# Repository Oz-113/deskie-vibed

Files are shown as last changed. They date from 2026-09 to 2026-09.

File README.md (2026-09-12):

# Deskie

I had deepseek create this project based on my initial prototype.

A desk-side volume and system-monitor controller for the **ESP32-S3 (N16R8)**, built around a
240 × 240 round **GC9A01** display. An animated background plays behind a set of radial gauges,
the rotary encoder drives the Windows volume and media transport, and the device is fed live
CPU / RAM / GPU data by a small Python bridge over the USB serial link.

> One USB cable, no extra wiring, no drivers: the board appears as a serial port and the
> Python script does the PC-side work.

---

## Features

* **Arc-based UI** over a dimmed, still-playing animation — resource gauges, detail pages,
  a volume gauge, transport controls and an animation picker all share one visual language.
* **Real Windows volume**, read *and* written, plus mute and the media keys
  (the firmware sends intent; the PC performs it).
* **Live metrics**: CPU load / clock / threads, RAM used-total, GPU load, GPU temperature,
  hotspot, memory temperature, GPU board power, fan speed, and VRAM used-total.
* **Now-playing ticker** on the idle screen with a rotating vector ornament, all tinted from
  the animation's palette.
* **Audio reactive spectrum**: eight log-spaced bands drawn as a mirrored radial ring over the
  upper half of the display, with a beat flash. All the DSP runs on the PC, so the board only
  receives eight small numbers.
* **Animations** stored in LittleFS as raw RGB565 frames, uploadable straight from the
  Arduino IDE.
* **Dual-core FreeRTOS firmware**: serial + input on core 0, rendering on core 1, with
  queues between them.
* **Graceful degradation on the PC side**: without LibreHardwareMonitor you still get CPU,
  RAM, GPU and VRAM usage from built-in Windows APIs.

---

## Architecture

```
   ┌────────────────────────────┐   USB-Converter serial (921600 8N1) ┌────────────────────┐
   │  ESP32-S3  N16R8           │ <─────────────────────────────────> │  PC                │
   │  GC9A01 240x240 round TFT  │                                     │  controller.py     │
   │  rotary encoder + buttons  │   metrics  ->  S,/E,/V,/T,          │  psutil            │
   │  LittleFS: RGB565 frames   │   commands <-  VSET,/MUTE,/MK,/REQ  │  LHM / PDH / pycaw │
   └────────────────────────────┘                                     └────────────────────┘
```

* The **PC** gathers metrics, owns the audio, and injects the media keys.
* The **board** owns the UI, the animation and all input, and never blocks on the link:
  it renders at its own pace and simply reflects the newest values it has.

---

## Repository layout

```
VolumeControllerUART/
├─ VolumeControllerUART.ino   setup + the three pinned FreeRTOS tasks
├─ config.h                   pins, animation palette, gauge geometry, timings
├─ state.h / state.cpp        shared runtime state + mutex + the two queues
├─ comms.h / comms.cpp        serial line protocol  (core 0)
├─ input.h / input.cpp        encoder ISR + buttons (core 0)
├─ display.h / display.cpp    TFT_eSPI wrapper: sprite, gauges, vector icons
├─ anim.h / anim.cpp          LittleFS frame player (core 1)
├─ ui.h / ui.cpp              screens, navigation state machine, rendering
├─ partitions.csv             custom partition layout (large LittleFS area)
├─ data/                      the animation frames (*.raw, 115200 B each)
└─ pc/
   ├─ controller.py           the headless PC bridge
   ├─ requirements.txt
   └─ README.md
```

---

## Hardware

| Function | GPIO | Notes |
|---|---|---|
| Display MOSI / SCLK | 11 / 12 | GC9A01, HSPI, 27 MHz |
| Display CS / DC / RST | 10 / 14 / 15 | configured in TFT_eSPI's `User_Setup.h` |
| Rotary encoder A / B | 5 / 4 | quadrature, interrupt driven |
| Encoder push button | 17 | short press = OK/enter, long press = back |
| Media play / next / prev | 6 / 7 / 8 | work from any screen, active-low |
| Shortcut: monitor | 21 | reserved, optional |
| Shortcut: volume | 38 | reserved, optional |
| Shortcut: media | 47 | reserved, optional |
| Shortcut: gallery | 48 | reserved, optional |

The display pins live in the **TFT_eSPI** library's `User_Setup.h`, not in this sketch — that is
normal for TFT_eSPI and keeps the driver configuration with the library.

The four "shortcut" pins are wired as `INPUT_PULLUP` and are active-low, so an **unwired pin
simply reads HIGH and never fires** — you can leave them unconnected and fit buttons later.
Set `ENABLE_SHORTCUT_BUTTONS 0` in `config.h` to release them.

The PC link uses the native USB port of the board (USB-CDC): one cable carries both flashing
and the data link.

---

## Build & flash

Arduino IDE 2.x, **esp32** board package **3.3.11**, board **ESP32S3 Dev Module**:

| Setting | Value |
|---|---|
| Flash Size | 16MB (128Mb) |
| PSRAM | OPI PSRAM |
| Partition Scheme | **Custom** (uses `partitions.csv`) |
| USB Mode | Hardware CDC and JTAG |
| **USB CDC On Boot** | **Enabled** |
| Upload Speed | 921600 |
| CPU Frequency | 240MHz |
| Loop Core | Core 1 *(default)* |

> `USB CDC On Boot` selects which USB port the firmware talks on. **Enabled** = the native
> USB-CDC port (labelled `USB` on most devkits). If you set it to **Disabled**, `Serial` moves
> to UART0 (GPIO43/44) and you must use the board's `UART` (CH34x/CP210x bridge) port instead.
> Getting this pair wrong is the one thing that makes the link look dead — see *Troubleshooting*.

Steps:

1. Open `VolumeControllerUART.ino`.
2. Upload the sketch.
3. Upload the filesystem (**Tools ▸ ESP32 LittleFS Data Upload**). `data/` holds the animation
   frames and is a few MB, so this takes a moment.
4. Start the PC bridge (below).

Typical footprint: **~418 KB flash, ~24 KB static RAM** plus two 115 KB PSRAM frame buffers.

---

## The serial protocol

Plain ASCII, one message per line, `\n`-terminated, comma separated. Every value is an integer
and **`-1` means "unavailable"**. Unrecognised lines (such as firmware boot logs) are ignored
by both sides.

### PC → board

| Message | Meaning |
|---|---|
| `H,<ver>` | handshake / protocol version (the board answers with its own `H,1`) |
| `S,<cpu>,<ram>,<gpu>,<vram>` | summary percentages |
| `E,<13 values>` | detail payload, fixed order (see below) |
| `V,<volume>,<mute>` | current master volume 0..100 and mute flag |
| `T,<state>,<artist>\|<title>` | now playing; state 0 none / 1 playing / 2 paused |
| `A,<b0>..<b7>,<pulse>` | audio spectrum: eight band levels (0..100) plus a beat pulse |
| `P` | ping (the board answers `PONG`) |

`E` field order:

| # | field | unit | # | field | unit |
|---|---|---|---|---|---|
| 0 | CPU temperature | ×10 | 7 | GPU hotspot | ×10 |
| 1 | CPU package power | ×10 | 8 | GPU memory temperature | ×10 |
| 2 | CPU clock | MHz | 9 | GPU board power | ×10 |
| 3 | CPU threads | count | 10 | GPU fan | % |
| 4 | RAM used | MB | 11 | VRAM used | MB |
| 5 | RAM total | MB | 12 | VRAM total | MB |
| 6 | GPU temperature | ×10 | | | |

### Board → PC

| Message | Meaning |
|---|---|
| `H,<ver>` | boot announce + reply to the PC handshake |
| `VSET,<n>` | absolute volume target from the volume wheel (0..100) |
| `VOL,±n` | relative step — still accepted by the PC, no longer sent by the board |
| `MUTE,<0\|1>` | toggle mute |
| `MK,PP` / `MK,N` / `MK,P` | media play-pause / next / previous |
| `REQ,<C\|R\|G\|V>` | "send the detail payload for CPU/RAM/GPU/VRAM" |
| `PG,<PAGE>` | which screen is open (`MONITOR`/`VOLUME`/`MEDIA`/`GALLERY`) |
| `PONG` | answer to `P` |

The link is considered down after 1.5 s without traffic; the monitor page shows `LINK DOWN` and
the board keeps re-announcing `H,1` every 2 s until it hears from the PC.

> Why `VSET` and not `VOL,±1`? `GetMasterVolumeLevelScalar()` on Windows lags slightly behind a
> write, so a PC-side read-modify-write drifts and can even move the volume the wrong way. The
> board already knows the value it wants, so it sends the absolute target and the PC just applies
> it.

---

## The PC bridge

Headless — no GUI, one process, run it whenever you want the board connected.

```powershell
cd pc
python -m venv .venv
.\.venv\Scripts\Activate.ps1
pip install -r requirements.txt

python controller.py --scan      # find the port the board actually answers on
python controller.py             # auto-detect and run (Ctrl+C to stop)
python controller.py --port COM5 -v
```

### Flags

| Flag | Purpose |
|---|---|
| `--port COM5` | pin the port (default: probe every port for the board) |
| `--list` | list serial ports with VID:PID |
| `--scan` | probe every port for the board and exit |
| `--selftest` | test master-volume read **and** write, then exit |
| `--rate N` | metric updates per second sent to the board (default 1) |
| `--audio-test` | print the live audio band levels (no serial port) and exit |
| `--audio-rate N` | spectrum updates per second sent to the board (default 25) |
| `--audio-gain DB` | extra gain applied to every band (default 0) |
| `--no-audio` | disable the audio reactive spectrum |
| `--np-proc NAME` | extra media process to watch for now playing (repeatable) |
| `--no-volume` / `--no-nowplaying` | disable those features |
| `--no-pdh` / `--no-lhm` | disable a GPU backend |
| `--lhm-dll PATH` | point at `LibreHardwareMonitorLib.dll` explicitly |
| `--dry-run` | exercise every backend without opening a port |
| `--run-seconds N` | exit after N seconds (handy for testing) |
| `--verbose` / `-v` | print every protocol line in both directions |

### Where the numbers come from

| Data | Source | Needed install |
|---|---|---|
| CPU load, clock, threads, RAM used/total | `psutil` | `pip install psutil` |
| GPU utilisation | LibreHardwareMonitor, else Windows PDH counters | none (PDH is built in) |
| VRAM used | LibreHardwareMonitor, else PDH `Dedicated Usage` | none |
| VRAM total | `HardwareInformation.qwMemorySize` from the registry | none |
| CPU / GPU temperature, hotspot, memory temp, board power, fan | LibreHardwareMonitor | **LibreHardwareMonitor** + `pip install pythonnet` |
| Master volume / mute | `pycaw` (Core Audio) | `pip install pycaw comtypes` |
| Media keys | `user32.keybd_event` | none |
| Now playing | Windows SMTC when `winsdk`/`winrt` is importable, else media window titles | none for the fallback |

Everything is layered, so a missing optional backend degrades to `--` on the display instead of
failing to start.

#### Installing the optional sensor backend

1. Download the latest release of
   [LibreHardwareMonitor](https://github.com/LibreHardwareMonitor/LibreHardwareMonitor) and
   extract the **whole folder** to `C:\Program Files\LibreHardwareMonitor\`
   (it must contain `LibreHardwareMonitorLib.dll`, `HidSharp.dll` and `WinRing0x64.sys`).
2. **Unblock the extracted files** — they carry Windows' "downloaded from the internet" mark and
   .NET then refuses to load the DLL (`0x80131515`, "network location"). In an **admin**
   PowerShell:

   ```powershell
   Get-ChildItem "C:\Program Files\LibreHardwareMonitor" -Recurse | Unblock-File
   ```
3. Run `LibreHardwareMonitor.exe` **as administrator** once, so its kernel driver is installed.
   Leaving it running is the simplest option.
4. `pip install pythonnet` and restart the bridge. It auto-detects the DLL and logs
   `LibreHardwareMonitor loaded: ...`; otherwise pass `--lhm-dll`.

---

## Screens & controls

**turn** = move / change value · **short press** = OK / enter · **long press** = back one level

| Screen | Shows | Controls |
|---|---|---|
| **IDLE** | the animation, the audio spectrum ring, and a now-playing ticker with a rotating vector ornament | turn = open the menu |
| **MENU** | four page tiles | turn = move, OK = open, hold = close |
| **MONITOR** | CPU / RAM / GPU / VRAM gauges spread around the ring, each with its `%`, the selected one large in the centre | turn = pick, OK = detail, hold = menu |
| **DETAIL** | one component full screen: big gauge plus temperature / power / clock / threads / used-total | turn = cycle component, hold = monitor |
| **VOLUME** | a big gauge driven by the real Windows volume | turn = adjust, OK = mute, hold = menu |
| **MEDIA** | now playing plus prev / play-pause / next | turn = pick, OK = go, hold = menu |
| **GALLERY** | a segmented ring with a live preview of each animation | turn = preview, OK = keep, hold = cancel |

The dimmed animation keeps playing behind every overlay, **MONITOR never times out**, `DETAIL`
falls back to `MONITOR` after 20 s, and the other pages return to the animation after 8 s of
inactivity. The four dedicated media buttons work from any screen.

---

## Firmware architecture

| Task | Core | Prio | Responsibility |
|---|---|---|---|
| `taskComm` | 0 | 4 | serial RX line assembly, TX queue drain, link watchdog |
| `taskInput` | 0 | 5 | encoder sampling, button debounce, short/long press |
| `taskRender` | 1 | 6 | frame load, dim, gauges, `pushSprite` |

* `taskInput` posts `InputEvent`s onto `gInputQ`; `uiRender()` pumps that queue and feeds each
  event to `uiHandleEvent()` before drawing.
* The renderer posts `OutMsg`s onto `gOutQ`; `taskComm` drains those to the PC.
* The only shared state is one `Runtime` struct behind a mutex, snapshotted once per frame.
* `loop()` is intentionally empty — all work is in the pinned tasks.

**Rendering budget.** The panel bus runs at 27 MHz, so a full 240 × 240 frame takes ~34 ms to
push; that caps the display at roughly **29 fps** whatever the animation's `fps` says. Rendering
is also "dirty" filtered: if neither a new frame was loaded nor any displayed value changed, the
frame simply is not re-pushed.

---

## Customising

Almost everything you would want to change lives in **`config.h`**.

### The colour palette

Each animation carries its own three colours, so the whole UI re-tints when you switch animation:

```cpp
struct GifPreset {
  const char* prefix;     // LittleFS filename prefix, without the "_n.raw"
  uint8_t     frames;     // number of frames on disk
  uint8_t     fps;        // target playback rate
  uint16_t    accent;     // main colour  (outlines, gauge track, labels)
  uint16_t    highlight;  // active colour (filled gauge, selection, now playing)
  uint16_t    tint;       // dark fill behind gauges
};
```

Colours are RGB565, e.g. `0xF800` = red, `0x07E0` = green, `0x001F` = blue.

### Adding an animation

1. Put the source frames in `source_frames/` (PNG/JPG, **240 × 240**, named so that a plain
   alphabetical sort puts them in playing order).
2. Run `python img_to_565.py` from the project root. It converts every image into a
   little-endian RGB565 dump in `data/`, keeping the base name — `mypic.png` → `data/mypic.raw`.
   If you want a specific prefix, either rename the images first or edit `img_to_565.py`.
3. Add **one line** to `GIF_TABLE[]` in `config.h`:

   ```cpp
   { "mypic",  24,  20,  0x07E0,  0x9FEA,  0x0A61 },   // prefix, frames, fps, accent, highlight, tint
   ```
   `frames` must equal the number of `.raw` files for that prefix.
4. Bump `GIF_COUNT` so it matches the number of rows in the table.
5. Re-upload the sketch, then re-upload the filesystem (LittleFS).

**Nothing in the UI has to change.** The gallery ring divides itself from `GIF_COUNT`, the
`n / N` counter and the centre label follow automatically, and the new palette entry tints every
screen when that animation is selected.

### Removing an animation

1. Delete its row from `GIF_TABLE[]` in `config.h`.
2. Decrement `GIF_COUNT`.
3. Optionally delete the matching `data/<prefix>_*.raw` files so the filesystem stays small.
4. Re-upload the sketch (and the filesystem if you removed files).

Keep `prefix` short-ish (under ~24 characters) — it is drawn in the centre of the gallery ring.
Also remember each frame costs 115 200 bytes: the LittleFS partition is ~13.4 MB, so about 115
frames fit in total.

### Audio reactive spectrum

The PC captures the **default output device** with WASAPI loopback (`pyaudiowpatch`), splits it
into `AUDIO_BANDS` log-spaced bands with a small biquad bank, applies auto-gain, detects beats and
sends `A,<b0>..<b7>,<pulse>` roughly 25 times a second. The board only draws the numbers:

| Define | Meaning |
|---|---|
| `ENABLE_SPECTRUM` | `0` to ignore the `A,` messages completely |
| `AUDIO_BANDS` | band count - must match `controller.py` |
| `SPEC_SEGMENTS` / `SPEC_GAP_DEG` | number of bars and the gap between them |
| `SPEC_R_INNER` / `SPEC_R_MAX` | bar length at 0 % and at 100 % |
| `SPEC_GAMMA` | `0.62` lifts mid levels so quiet bands still show |
| `SPEC_START_DEG` / `SPEC_END_DEG` | the arc the bars occupy (default: the upper half, which leaves the bottom free for the ticker) |
| `SPEC_PULSE_R` / `SPEC_PULSE_W` | beat ring radius and thickness |

PC-side knobs worth knowing:

* `--audio-test` - print the eight levels live (no board needed) to check the capture;
* `--audio-rate` - updates per second (lower it if the animation looks starved);
* `--audio-gain DB` - manual boost on top of the auto-gain (try `+10` for very quiet mixes).

### Gauge geometry and timings

| Group | What it controls |
|---|---|
| `MON_*` | the four monitor gauges: radius, thickness, arc length, gap, label/value radii |
| `BIG_*` | the large gauge used by DETAIL and VOLUME (radius, sweep start/end) |
| `GAL_*` | the gallery ring (radii and the gap between segments) |
| `MENU_*` | tile size and corner radius |
| `IDLE_SPIN_PERIOD_MS` | one full turn of the idle now-playing ornament |
| `UI_IDLE_TIMEOUT_MS` / `UI_DETAIL_TIMEOUT_MS` | auto-return timers |
| `LONGPRESS_MS` / `BTN_DEBOUNCE_MS` | button feel |
| `RX_STALE_MS` | how long without PC traffic before the link is flagged down |
| `CORE_*`, `TASK_*` | task affinity, priority and stack sizes |

### Volume step size

The wheel sends the **absolute** target on every detent, so the step size lives in the firmware —
`ui.cpp`, `onEncoder()`, `case MODE_VOLUME`:

```cpp
gState.volume = (int16_t)constrain((int)gState.volume + dir, 0, 100);
```

`dir` is ±1 per detent. For 2 % per detent:

```cpp
gState.volume = (int16_t)constrain((int)gState.volume + dir * 2, 0, 100);
```

> Changing `+1`/`-1` in `controller.py` no longer affects the wheel: that code path only serves
> the legacy relative `VOL,±n` message, which the board no longer sends. Likewise `--rate` only
> controls how often metrics are pushed, not the volume.

### Changing the fonts

All drawing happens on a 16-bit **sprite**, and every text call passes its font explicitly:

```cpp
spr.drawString(txt, x, y, font);        // display.cpp
```

So a single `tft.setFont(...)` / `spr.setTextFont(...)` in `setup()` will **not** re-font the UI —
the per-call font number wins. To restyle, edit the font numbers at the call sites: the small
literals in `display.cpp` (`dispTextCentre`, `dispTextAt`, `dispToast`) and in `ui.cpp`
(`drawIdle`, `drawMenu`, `drawMonitor`, `drawDetail`, `drawVolume`, `drawMedia`, `drawGallery`).

| Font | Size | Used for |
|---|---|---|
| 1 | 8 px | small labels, hints, artist line |
| 2 | 16 px | page names, titles, component names |
| 4 | 26 px | per-gauge percentage values |
| 6 | 48 px | monitor centre reading |
| 7 | 48 px | DETAIL / VOLUME big reading |

TFT_eSPI only compiles the fonts enabled in its `User_Setup.h` (1, 2, 4, 6, 7 and 8 by default).
A genuinely different typeface means enabling `LOAD_GFXFF` there and using `setFreeFont()` with an
Adafruit-GFX font.

A tidy way to make restyling a one-line change is to add `UI_FONT_SMALL` / `UI_FONT_MID` /
`UI_FONT_BIG` to `config.h` and swap the literals for them.

---

## Notes & limitations

* The panel bus runs at 27 MHz, so a full frame takes ~34 ms to push — the practical ceiling is
  about **29 fps**. The `fps` field in `GIF_TABLE` is a target; 20–30 is realistic.
* Now playing falls back to **window titles** when `winsdk`/`winrt` is unavailable. It scans every
  window (including players minimised to the tray), ignores Windows helper windows, and *scores*
  the candidates — a browser tab with a known site beats a generic window — so a title such as
  `Anything | YouTube Music - Brave` becomes `Anything`. That fallback always reports "playing"
  (Windows does not expose pause state without SMTC). If a player is not recognised, run with `-v`
  to see the candidates and add it with `--np-proc yourplayer.exe`.
* `winsdk` currently has no wheel for Python 3.14, so on that interpreter the bridge uses the
  window-title fallback. To get real SMTC metadata (artist, play state), build the venv with
  Python 3.12/3.13 and `pip install winsdk` — it is picked up automatically.
* LibreHardwareMonitor needs its kernel driver: launch the application once as administrator.
  Without it the bridge still reports CPU/RAM/GPU/VRAM usage, and the temperature, power and fan
  fields show `--`.
* The four shortcut buttons are optional and unconnected by default.
* The audio spectrum needs `pyaudiowpatch` (`pip install pyaudiowpatch`); without it the bridge
  logs a note and never sends `A,` messages. It captures the **default output device**, so
  whatever Windows is playing is what you see. The auto-gain tracks the loudest band, so the
  display looks right at any system volume, and it stays silent below the noise gate.

---

## Troubleshooting

### The PC log shows only `->` lines and no `<-` lines

The board and the PC are not talking. The UI and the animation are local to the firmware, so they
keep working — the giveaway is that the board keeps re-sending `H,1` and the PC never logs
`<- H,1`.

The ESP32-S3 has **two** USB ports and the firmware only talks on the one that matches
**`USB CDC On Boot`**:

| `USB CDC On Boot` | Firmware `Serial` is on | Cable must be in |
|---|---|---|
| **Enabled** | native USB-CDC (GPIO19/20) | the port labelled **USB** |
| **Disabled** | UART0 (GPIO43/44) | the port labelled **UART** (CH34x/CP210x bridge) |

A CH34x/CP210x entry in `--list` is the **bridge** port; an Espressif device with VID `303A` is
the **native USB**. Let the script find it:

```powershell
python controller.py --scan

  probing COM3     ... no answer
  probing COM7     ... answered

board answered on COM7  ->  use --port COM7
```

Either move the cable to the other port so it matches the setting, or change `USB CDC On Boot`
and re-flash. You must then see, within ~2 s:

```
[..] board handshake received
  <- H,1
```

Independent check: open the Arduino IDE **Serial Monitor at 115200** on the port and press the
board's **RST** button — you should see the boot banner with the storage report.

### The volume wheel does nothing, or jumps

1. Confirm the link first (above) — the PC only ever sees `VSET,` if the link is up.
2. `python controller.py --selftest` must print `volume read/write OK`.
3. Run the bridge **without** administrator rights; Core Audio needs no elevation.
4. The bridge re-sends the volume every 3 s, so the gauge resyncs by itself, and if a Core Audio
   write ever fails it falls back to tapping the system volume keys.

### `Cannot change thread mode after it is set` (`0x80010106`)

Importing **pythonnet** (the LibreHardwareMonitor backend) initialises the main thread as MTA, and
comtypes/pycaw then cannot switch it to STA. The bridge works around this by running every Core
Audio call on its own dedicated STA worker thread; if you see this error you are running an older
copy of `controller.py`.

### `0x80131515` / "network location" when loading LibreHardwareMonitor

The extracted DLL is blocked by Windows ("mark of the web"). Fix it once in an **admin**
PowerShell, then restart the bridge:

```powershell
Get-ChildItem "C:\Program Files\LibreHardwareMonitor" -Recurse | Unblock-File
```

### Metric readings show `--`

* `-1` is the protocol's "unavailable" sentinel, so `--` simply means the PC has no value yet.
* CPU/RAM/GPU/VRAM should always be present; if they are not, check that `psutil` is installed and
  that the link is up (above).
* Temperatures, power and fan come from LibreHardwareMonitor — see the install notes above.

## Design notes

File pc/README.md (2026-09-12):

# `controller.py` - PC side bridge

Headless service that feeds the ESP32-S3 controller and executes what the wheel and
buttons ask for. No GUI.

## Install

```powershell
python -m venv .venv
.\.venv\Scripts\Activate.ps1          # PowerShell
pip install -r requirements.txt
```

The mandatory set is `pyserial`, `psutil`, `pycaw` + `comtypes` (volume and media keys) and
`pyaudiowpatch` (audio spectrum). `pythonnet` is optional but recommended - with
LibreHardwareMonitor installed it adds temperatures, hotspot, board power, fan speed and exact
VRAM.

## Run

```powershell
python controller.py --list                 # list COM ports
python controller.py --port COM5            # start (Ctrl+C stops)
python controller.py                        # auto-detect the Espressif USB-CDC port
```

Handy for testing without hardware:

```powershell
python controller.py --dry-run --run-seconds 10 -v
```

## What it does

* pushes `S,` (summary, 4 Hz) and `E,` (detail, 1 Hz) to the board,
* mirrors the Windows master volume with `V,` and applies `VOL`/`VSET`/`MUTE` coming
  back from the board,
* injects the media keys for `MK,PP` / `MK,N` / `MK,P`,
* reports the current track with `T,`,
* captures the system audio and pushes the eight-band spectrum plus beat pulse with `A,`.

## Audio spectrum

`pyaudiowpatch` records the **default output device** through WASAPI loopback; a small biquad bank
splits it into eight log-spaced bands, auto-gain scales them to the current loudness and an
envelope detector produces the beat pulse. You can check the capture on its own, with no board
attached:

```powershell
python controller.py --audio-test
```

It prints the eight levels ten times a second - they should move with the music:

```
  [ 29  21  10   6   7   3   0   0]  beat=  0  ........
  [ 38  22   8   0   0   3  10   4]  beat=100  +.......
```

If the levels barely move, add gain (`--audio-gain 10`). If the animation on the board looks
starved, lower the send rate (`--audio-rate 15`).

## Files

| File | Purpose |
|---|---|
| `controller.py` | the service (serial link, backends, protocol, CLI) |
| `requirements.txt` | pip dependencies |

See `../README.md` for the full protocol and architecture description.

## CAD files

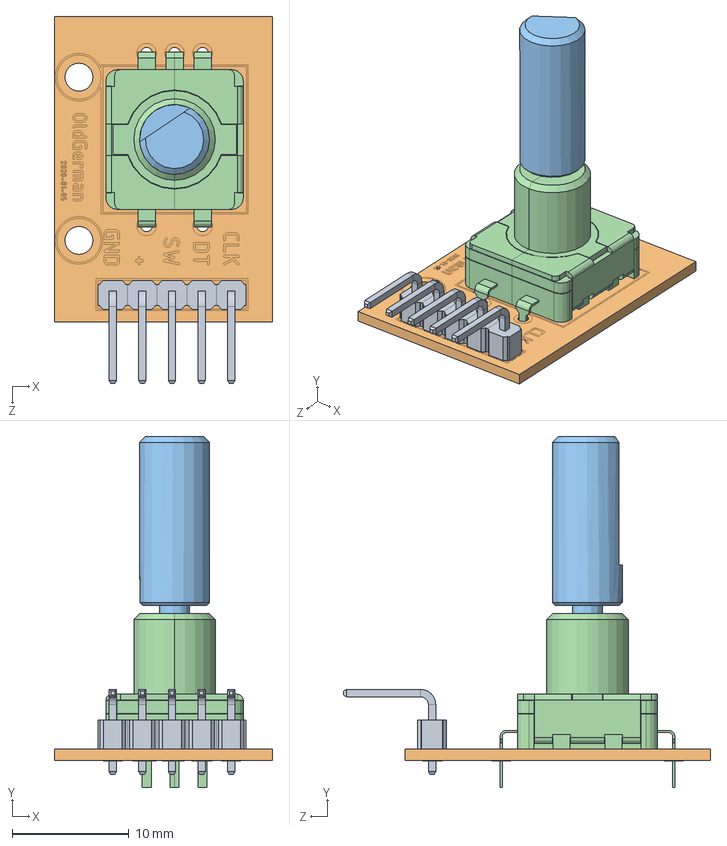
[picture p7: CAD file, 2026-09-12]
CAD/hazir parcalar/ky-040-rotary-encoder-1.snapshot.1/Rotary Encoder - ODG/sw2017 model/KY-040 Rotary Encoder.SLDASM
18.7 x 30.1 x 31.5 mm
Rotary Encoder
D-handle
pcb
2.54 5PIN 90

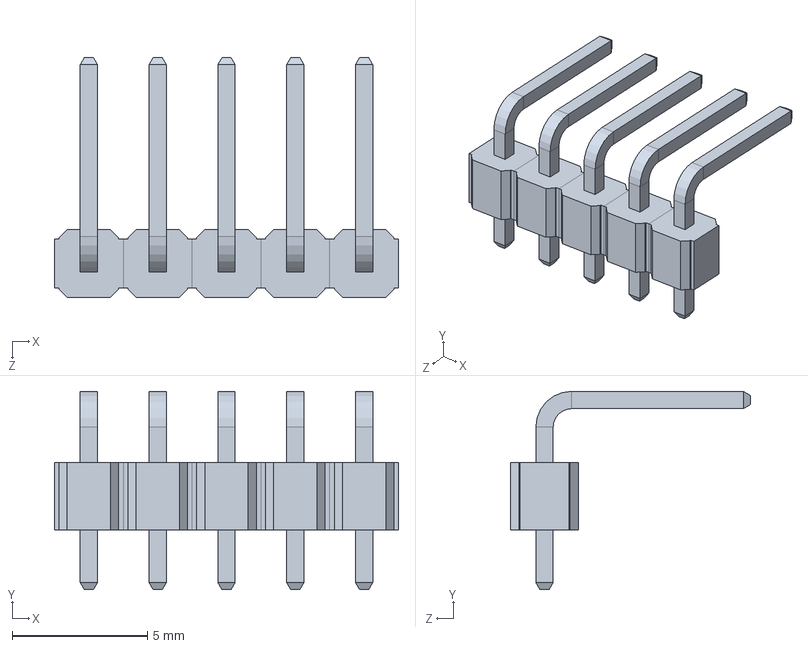
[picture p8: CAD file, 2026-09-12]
CAD/hazir parcalar/ky-040-rotary-encoder-1.snapshot.1/Rotary Encoder - ODG/sw2017 model/2.54 5PIN 90.SLDPRT
12.7 x 7.32 x 8.85 mm

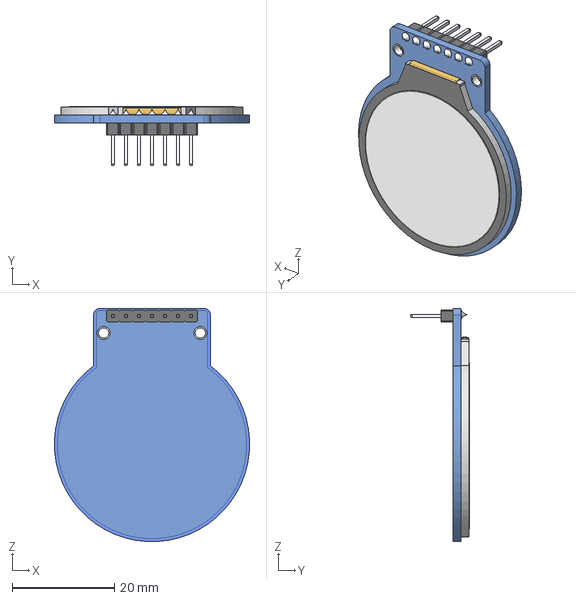
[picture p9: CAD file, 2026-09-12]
CAD/hazir parcalar/teyleten-robot-gc9a01-1.snapshot.4/Teyleten Robot 1.28 Inch GC9A01 240x240 v1.step
38.1 x 11.5 x 45.5 mm

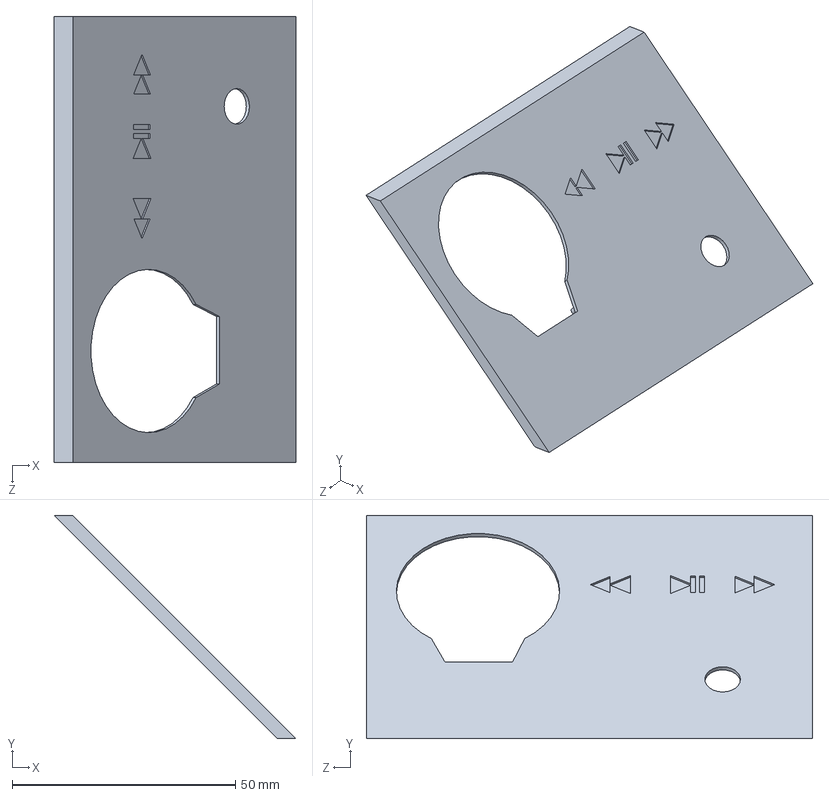
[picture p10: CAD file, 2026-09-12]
CAD/frontplate.SLDPRT
54.2 x 50.0 x 100.0 mm

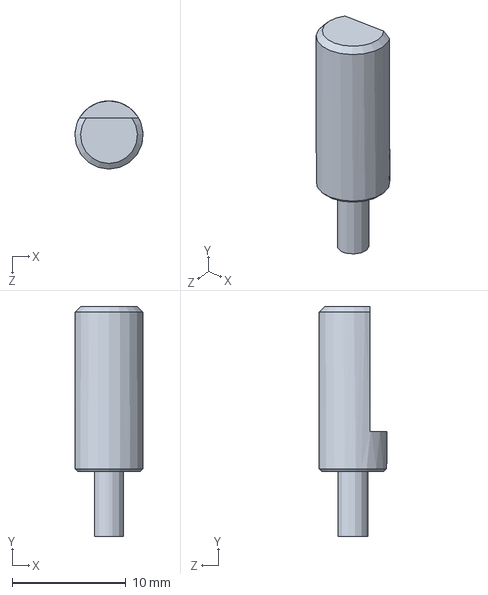
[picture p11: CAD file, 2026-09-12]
CAD/hazir parcalar/ky-040-rotary-encoder-1.snapshot.1/Rotary Encoder - ODG/sw2017 model/D-handle.SLDPRT
6.00 x 20.2 x 6.00 mm

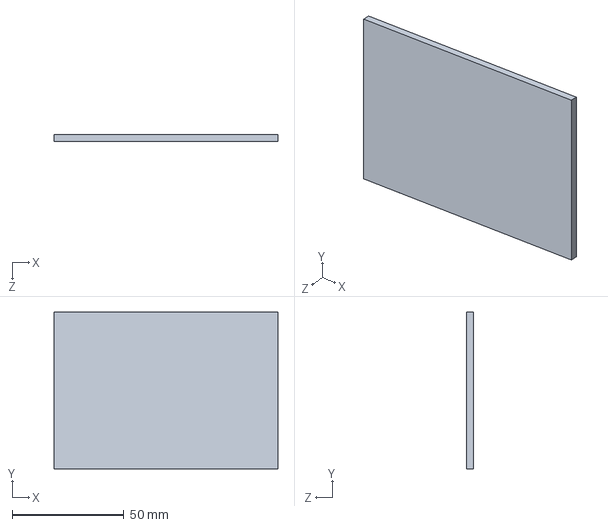
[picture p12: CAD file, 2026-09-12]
CAD/baseplate.SLDPRT
100.0 x 70.0 x 3.00 mm

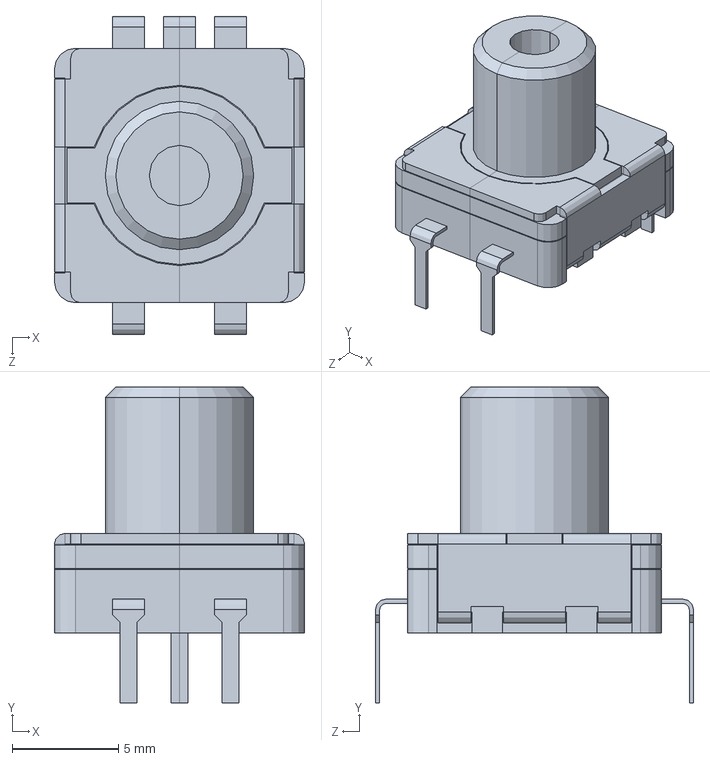
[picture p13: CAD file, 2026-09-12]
CAD/hazir parcalar/ky-040-rotary-encoder-1.snapshot.1/Rotary Encoder - ODG/sw2017 model/Rotary Encoder.SLDPRT
11.8 x 14.9 x 15.0 mm

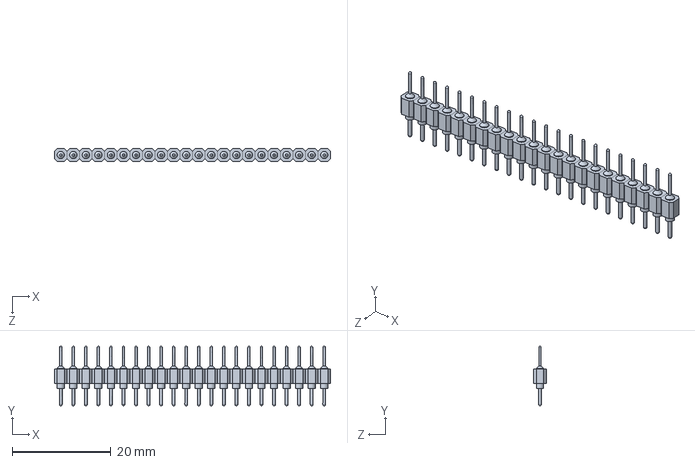
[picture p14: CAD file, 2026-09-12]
CAD/hazir parcalar/esp32-s3-wroom-1-1.snapshot.2/Штыревой разъем 22 конт шаг 2.54мм.SLDPRT
55.9 x 12.1 x 2.54 mm

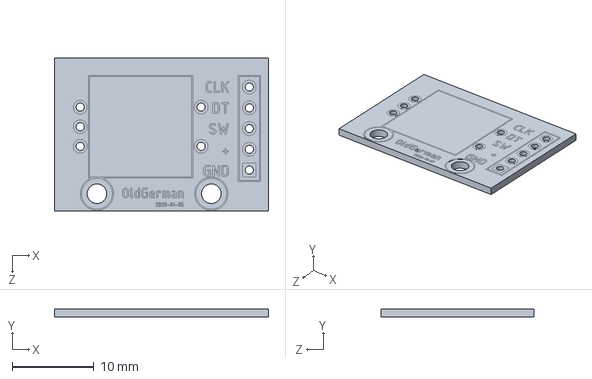
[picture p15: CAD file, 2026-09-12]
CAD/hazir parcalar/ky-040-rotary-encoder-1.snapshot.1/Rotary Encoder - ODG/sw2017 model/pcb.SLDPRT
26.2 x 1.02 x 18.7 mm

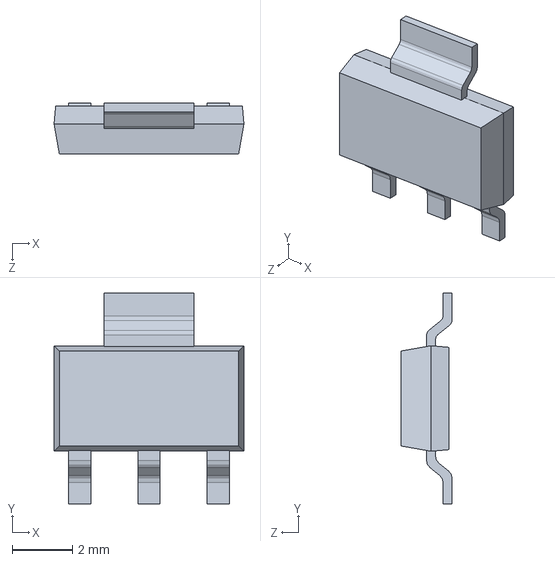
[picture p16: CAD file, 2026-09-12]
CAD/hazir parcalar/esp32-s3-wroom-1-1.snapshot.2/SOT-223.SLDPRT
6.30 x 7.00 x 1.70 mm

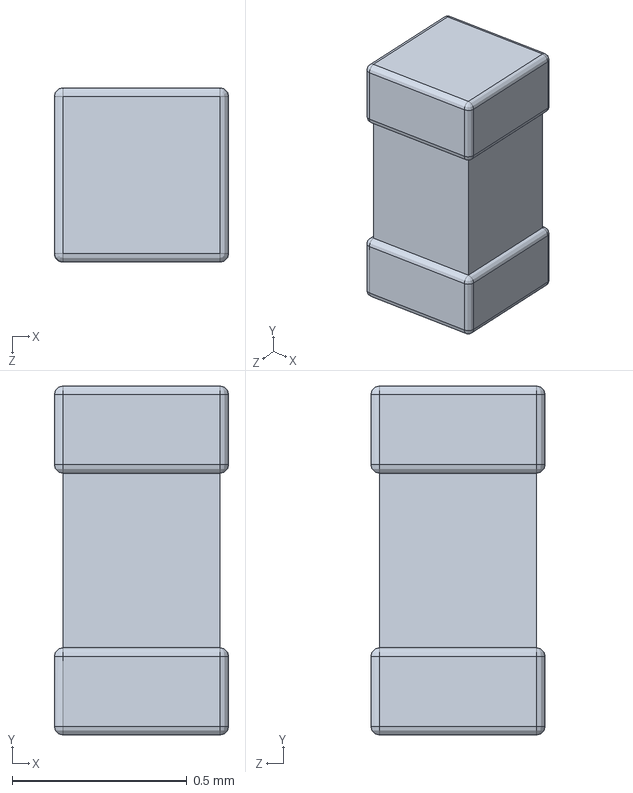
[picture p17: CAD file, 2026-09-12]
CAD/hazir parcalar/esp32-s3-wroom-1-1.snapshot.2/0402_CA_CB_CC_CD.SLDPRT
0.5 x 1.00 x 0.5 mm

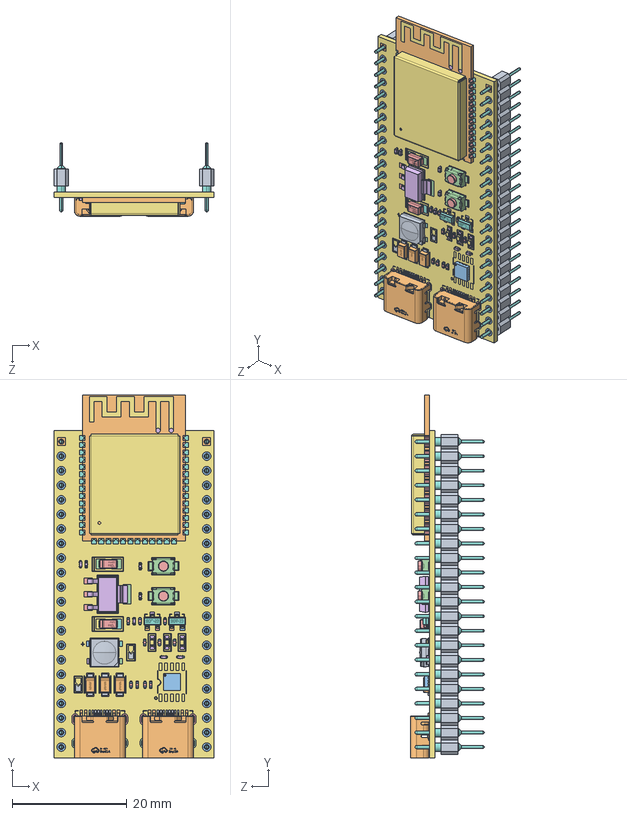
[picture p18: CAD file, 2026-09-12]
CAD/hazir parcalar/esp32-s3-wroom-1-1.snapshot.2/ESP32-S3-WROOM-1.STEP
27.9 x 63.4 x 12.9 mm
ESP32-S3-WROOM-1
Штыревой разъем 22 конт шаг 2.54мм x 2
USB-C_SMD-TYPE-C-31-M-12~USB-C_SMD-TYPE-C-31-M-12~QTmk.step.STEP x 2
2025-08-30-17-43-03-310.step.STEP x 2
WS2812B
SOT-223
SOT23-3 x 2
SOD-123F x 3
QFN-16 (3x3) Part1.stp
QFN-16 (3x3) Part2.stp x 16
ctantal_case-a_l3-2_w1-6_h1-6 x 2
Body.step x 3
Cover.step x 3
Cover_Mini.step x 3
Insides.step x 3
RC0402 x 10
0402_CA_CB_CC_CD x 7

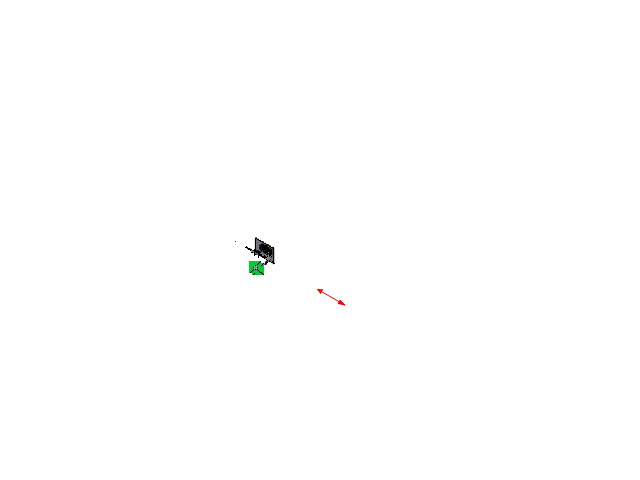
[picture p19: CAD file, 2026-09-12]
CAD/AllAssembly.SLDASM
Rotary Encoder
D-handle
pcb
2.54 5PIN 90
ESP32-S3-WROOM-1
Штыревой разъем 22 конт шаг 2.54мм x 2
USB-C_SMD-TYPE-C-31-M-12~USB-C_SMD-TYPE-C-31-M-12~QTmk.step.STEP x 2
2025-08-30-17-43-03-310.step.STEP x 2
WS2812B
SOT-223
SOT23-3 x 2
SOD-123F x 3
QFN-16 (3x3) Part1.stp
QFN-16 (3x3) Part2.stp x 16
eBom-FreeParts.stp
ctantal_case-a_l3-2_w1-6_h1-6 x 2
Body.step x 3
Cover.step x 3
Cover_Mini.step x 3
Insides.step x 3
RC0402 x 10
0402_CA_CB_CC_CD x 7
baseplate
Component5_1.step
TFT-Round-1.28 v1-0_1.step
TFT-Round-1.28 v1-1_1.step
Component4_1.step
Component6-2_1.step
Component6-3_1.step
Component6-4_1.step
Component6-5_1.step
Component6-6_1.step
Component6-7_1.step
Component6-8_1.step
eBom-FreeParts_1.step
frontplate

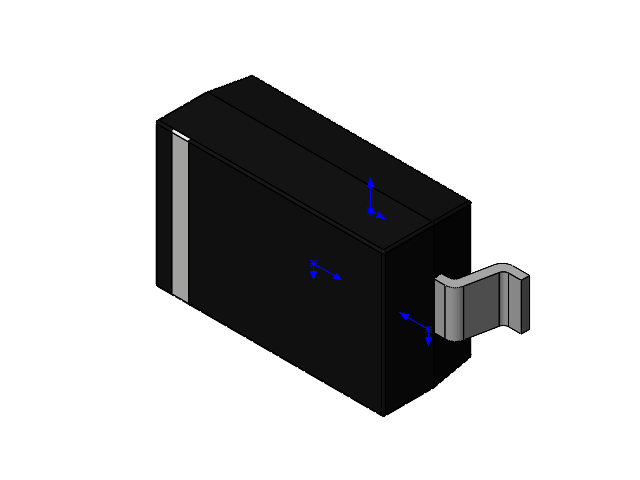
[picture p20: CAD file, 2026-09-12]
CAD/hazir parcalar/esp32-s3-wroom-1-1.snapshot.2/sod123 v4.SLDASM
pin.step
pin(Mirror).step
icbody_1.step
Component5.step

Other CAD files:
CAD/hazir parcalar/esp32-s3-wroom-1-1.snapshot.2/Кнопка.SLDASM
CAD/hazir parcalar/esp32-s3-wroom-1-1.snapshot.2/USB-C.SLDASM
CAD/hazir parcalar/esp32-s3-wroom-1-1.snapshot.2/QFN-16 (3x3).SLDASM
CAD/hazir parcalar/esp32-s3-wroom-1-1.snapshot.2/LED_0603 v4.SLDASM
CAD/hazir parcalar/esp32-s3-wroom-1-1.snapshot.2/ESP32-S3-WROOM-1.SLDASM
CAD/hazir parcalar/esp32-s3-wroom-1-1.snapshot.2/RC0402.SLDPRT
CAD/hazir parcalar/esp32-s3-wroom-1-1.snapshot.2/SOD-123F.SLDPRT
CAD/hazir parcalar/esp32-s3-wroom-1-1.snapshot.2/SOT23-3.SLDPRT
CAD/hazir parcalar/esp32-s3-wroom-1-1.snapshot.2/WS2812B.SLDPRT
CAD/hazir parcalar/esp32-s3-wroom-1-1.snapshot.2/ctantal_case-a_l3-2_w1-6_h1-6.SLDPRT
CAD/hazir parcalar/teyleten-robot-gc9a01-1.snapshot.4/Teyleten Robot 1.28 Inch GC9A01 240x240 v1.SLDASM
CAD/hazir parcalar/teyleten-robot-gc9a01-1.snapshot.4/Teyleten Robot 1.28 Inch GC9A01 240x240 v1.f3d

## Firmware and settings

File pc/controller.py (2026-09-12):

#!/usr/bin/env python3
"""
============================================================================
 controller.py - PC side bridge for the ESP32-S3 UART Volume Controller
============================================================================
 Headless replacement for the old USB-HID firmware. It

   * reads CPU / RAM / GPU / VRAM / temperature / power / fan data,
   * reads and changes the Windows master volume,
   * injects the media keys,
   * reports the currently playing track,
   * and talks to the board with a simple line protocol over the USB
     serial port (the same cable the old HID build used).

 Run with --list to see the available COM ports, then:

     python controller.py --port COM5

 See README.md for the full protocol description.
============================================================================
"""

from __future__ import annotations

import argparse
import ctypes
import ctypes.wintypes as wt
import math
import os
import queue
import struct
import sys
import threading
import time
from dataclasses import dataclass

# ---------------------------------------------------------------------------
# Protocol constants - these MUST match firmware config.h / comms.cpp
# ---------------------------------------------------------------------------
PROTO_VERSION = 1

SUMMARY_HZ   = 1.0      # S,<cpu>,<ram>,<gpu>,<vram>  (default; --rate overrides)
DETAIL_HZ    = 1.0      # E,<13 values>                (default; --rate overrides)
VOLUME_HZ    = 4.0      # V,<volume>,<mute>
VOLUME_RESYNC_S = 3.0   # re-send the volume even if unchanged (self-healing)
NOWPLAY_HZ   = 1.0      # T,<state>,<artist>|<title>
HELLO_HZ     = 2.0      # H,<ver> until the board answers

NA = -1                 # "not available" sentinel used by the firmware


# ---------------------------------------------------------------------------
# Small helpers
# ---------------------------------------------------------------------------
def log(msg: str) -> None:
    print(f"[{time.strftime('%H:%M:%S')}] {msg}", flush=True)


def clamp(v: float, lo: float = 0.0, hi: float = 100.0) -> int:
    return int(max(lo, min(hi, v)))


@dataclass
class Metrics:
    """One complete snapshot; every field is an int, NA == unavailable."""
    cpu: int = NA
    ram: int = NA
    gpu: int = NA
    vram: int = NA

    cpu_temp_x10: int = NA
    cpu_power_x10: int = NA
    cpu_freq_mhz: int = NA
    cpu_cores: int = NA

    ram_used_mb: int = NA
    ram_total_mb: int = NA

    gpu_temp_x10: int = NA
    gpu_hot_x10: int = NA
    gpu_memtemp_x10: int = NA
    gpu_power_x10: int = NA
    gpu_fan: int = NA

    vram_used_mb: int = NA
    vram_total_mb: int = NA

    def summary_line(self) -> str:
        return f"S,{self.cpu},{self.ram},{self.gpu},{self.vram}"

    def detail_line(self) -> str:
        # order MUST match state.cpp / the README table
        return ("E," + ",".join(str(v) for v in (
            self.cpu_temp_x10, self.cpu_power_x10, self.cpu_freq_mhz, self.cpu_cores,
            self.ram_used_mb, self.ram_total_mb,
            self.gpu_temp_x10, self.gpu_hot_x10, self.gpu_memtemp_x10,
            self.gpu_power_x10, self.gpu_fan,
            self.vram_used_mb, self.vram_total_mb,
        )))


@dataclass
class NowPlaying:
    state: int = 0          # 0 none, 1 playing, 2 paused
    artist: str = ""
    title: str = ""

    def line(self) -> str:
        # keep the payload free of separators the firmware uses
        a = self.artist.replace(",", " ").replace("|", " ")[:31]
        t = self.title.replace(",", " ").replace("|", " ")[:39]
        return f"T,{self.state},{a}|{t}"


# ---------------------------------------------------------------------------
# libc / user32 for media keys and window titles (no third-party deps)
# ---------------------------------------------------------------------------
_user32 = ctypes.windll.user32

VK_MEDIA_NEXT_TRACK = 0xB0
VK_MEDIA_PREV_TRACK = 0xB1
VK_MEDIA_STOP       = 0xB2
VK_MEDIA_PLAY_PAUSE = 0xB3
VK_VOLUME_DOWN      = 0xAE
VK_VOLUME_UP        = 0xAF
KEYEVENTF_KEYUP     = 0x0002


def _send_vk(vk: int) -> None:
    _user32.keybd_event(vk, 0, 0, 0)
    time.sleep(0.01)
    _user32.keybd_event(vk, 0, KEYEVENTF_KEYUP, 0)


# ---------------------------------------------------------------------------
# Serial link
# ---------------------------------------------------------------------------
def list_ports() -> list:
    try:
        from serial.tools import list_ports as lp
    except Exception:
        log("pyserial is not installed - run: pip install -r requirements.txt")
        return []
    return list(lp.comports())


def autodetect_port() -> str | None:
    """Prefer an Espressif CDC/JTAG device, then any USB serial port."""
    ports = list_ports()
    for p in ports:
        if p.vid == 0x303A:                       # Espressif
            return p.device
    for p in ports:
        desc = (p.description or "").lower()
        if "usb" in desc or "jtag" in desc or "cdc" in desc:
            return p.device
    return ports[0].device if ports else None


def probe_port(port: str, baud: int, timeout: float = 1.5) -> bool:
    """Open 'port', poke the board with a ping and see whether it answers."""
    try:
        import serial
    except Exception:
        return False
    try:
        s = serial.Serial(port=port, baudrate=baud, timeout=0, write_timeout=0.5)
    except Exception:
        return False
    try:
        time.sleep(0.1)
        s.reset_input_buffer()
        buf = b""
        deadline = time.time() + timeout
        while time.time() < deadline:
            s.write(b"P\n")                        # firmware answers PONG
            time.sleep(0.2)
            n = s.in_waiting
            if n:
                buf += s.read(n)
                if b"PONG" in buf or b"H," in buf:
                    return True
        return False
    except Exception:
        return False
    finally:
        try:
            s.close()
        except Exception:
            pass


def scan_for_board(baud: int) -> str | None:
    """
    Return the first serial port that actually speaks the protocol.

    This is the reliable way to find the right port: the ESP32-S3 exposes TWO
    USB ports (native USB-CDC and the on-board UART bridge) and only one of them
    matches the firmware's 'USB CDC On Boot' setting.
    """
    ports = list_ports()
    if not ports:
        return None
    ordered = sorted(ports, key=lambda p: 0 if p.vid == 0x303A else 1)
    for p in ordered:
        print(f"  probing {p.device:8} ...", end=" ", flush=True)
        ok = probe_port(p.device, baud)
        print("answered" if ok else "no answer", flush=True)
        if ok:
            return p.device
    return None


class Link:
    """Non-blocking line oriented serial link (with a dry-run mode)."""

    def __init__(self, port: str | None, baud: int, dry_run: bool, verbose: bool):
        self.dry      = dry_run
        self.verbose  = verbose
        self.rx       = bytearray()
        self.ser      = None
        self.board_hello = False

        if dry_run:
            log("dry-run: no serial port will be opened")
            return

        try:
            import serial
        except Exception:
            log("pyserial is not installed - run: pip install -r requirements.txt")
            raise SystemExit(2)

        if port is None:
            log("auto-detecting the board (probing every serial port) ...")
            found = scan_for_board(baud)
            if found:
                port = found
                log(f"board answered on {port}")
            else:
                port = autodetect_port()
                if port is None:
                    log("no serial port found - use --list and --port")
                    raise SystemExit(2)
                log(f"WARNING: no port answered the handshake, using {port} anyway")
                log("         no '<- H,1' lines within a few seconds means the")
                log("         cable is in the wrong USB port (see README 4/11).")

        self.ser = serial.Serial(port=port, baudrate=baud, timeout=0,
                                 write_timeout=0.5)
        self.ser.reset_input_buffer()
        self.ser.reset_output_buffer()
        log(f"opened {port} @ {baud}")

    def write(self, line: str) -> None:
        if self.verbose:
            print(f"  -> {line}", flush=True)
        if self.dry:
            return
        try:
            self.ser.write((line + "\n").encode("ascii", "replace"))
        except Exception as e:                    # never let the loop die
            log(f"write failed: {e}")

    def read_lines(self) -> list[str]:
        if self.dry:
            return []
        try:
            n = self.ser.in_waiting
            if n:
                self.rx.extend(self.ser.read(n))
        except Exception as e:
            log(f"read failed: {e}")
            return []

        lines = []
        while True:
            i = self.rx.find(b"\n")
            if i < 0:
                break
            raw = bytes(self.rx[:i]).decode("ascii", "ignore").strip()
            del self.rx[: i + 1]
            if raw:
                lines.append(raw)
        if len(self.rx) > 8192:                   # guard against garbage floods
            del self.rx[:-256]
        return lines

    def close(self) -> None:
        if self.ser is not None:
            try:
                self.ser.close()
            except Exception:
                pass


# ---------------------------------------------------------------------------
# CPU / RAM - psutil is the mandatory dependency
# ---------------------------------------------------------------------------
class PsutilBackend:
    def __init__(self) -> None:
        self.ok = False
        try:
            import psutil
            self.psutil = psutil
            self.ok = True
        except Exception:
            log("psutil is not installed - CPU/RAM will be unavailable")

    def apply(self, m: Metrics) -> None:
        if not self.ok:
            return
        ps = self.psutil
        try:
            m.cpu = clamp(ps.cpu_percent(interval=None))
            vm = ps.virtual_memory()
            m.ram = clamp(vm.percent)
            m.ram_used_mb  = int(vm.used / (1024 * 1024))
            m.ram_total_mb = int(vm.total / (1024 * 1024))
        except Exception:
            pass
        try:
            f = ps.cpu_freq()
            if f:
                m.cpu_freq_mhz = int(f.current)
        except Exception:
            pass
        try:
            m.cpu_cores = ps.cpu_count(logical=True)
        except Exception:
            pass

    def prime(self) -> None:
        """First cpu_percent() call always returns 0.0 - warm it up."""
        if self.ok:
            self.psutil.cpu_percent(interval=None)


# ---------------------------------------------------------------------------
# Mark-of-the-web removal
#   A DLL extracted from a downloaded ZIP carries a "Zone.Identifier" ADS.
#   .NET then refuses to LoadFrom it with 0x80131515 ("network location"),
#   which is exactly what LibreHardwareMonitorLib.dll hits. DeleteFileW on
#   "<file>:Zone.Identifier" strips the mark - the same thing Unblock-File does.
# ---------------------------------------------------------------------------
def _unblock_zone(path: str) -> bool:
    try:
        return bool(ctypes.windll.kernel32.DeleteFileW(f"{path}:Zone.Identifier"))
    except Exception:
        return False


def _has_zone(path: str) -> bool:
    """True when the file still carries a Zone.Identifier (blocked) stream."""
    try:
        attrs = ctypes.windll.kernel32.GetFileAttributesW(f"{path}:Zone.Identifier")
        return attrs != 0xFFFFFFFF
    except Exception:
        return False


def _unblock_folder(folder: str) -> int:
    cleared = 0
    try:
        for root, _dirs, files in os.walk(folder):
            for f in files:
                if _unblock_zone(os.path.join(root, f)):
                    cleared += 1
    except Exception:
        pass
    return cleared


def _blocked_count(folder: str) -> int:
    n = 0
    try:
        for root, _dirs, files in os.walk(folder):
            for f in files:
                if _has_zone(os.path.join(root, f)):
                    n += 1
    except Exception:
        pass
    return n


# ---------------------------------------------------------------------------
# LibreHardwareMonitor backend
#   Recommended: it is the only driver-free way to get AMD GPU temperature,
#   hotspot, board power, fan speed and VRAM totals on Windows.
#   Install LibreHardwareMonitor (it ships LibreHardwareMonitorLib.dll) or
#   point --lhm-dll at the DLL.
# ---------------------------------------------------------------------------
class LhmBackend:
    DEFAULT_PATHS = (
        r"C:\Program Files\LibreHardwareMonitor\LibreHardwareMonitorLib.dll",
        r"C:\Program Files (x86)\LibreHardwareMonitor\LibreHardwareMonitorLib.dll",
        os.path.expandvars(r"%LOCALAPPDATA%\LibreHardwareMonitor\LibreHardwareMonitorLib.dll"),
        os.path.expandvars(r"%USERPROFILE%\LibreHardwareMonitor\LibreHardwareMonitorLib.dll"),
    )

    def __init__(self, dll: str | None = None) -> None:
        self.ok       = False
        self.computer = None

        if dll is None:
            for p in self.DEFAULT_PATHS:
                if os.path.isfile(p):
                    dll = p
                    break
        if dll is None or not os.path.isfile(dll):
            log("LibreHardwareMonitor not found - GPU temps/power/VRAM unavailable")
            return

        try:
            import clr                                     # pythonnet
            dll = os.path.abspath(dll)
            folder = os.path.dirname(dll)

            # .NET refuses to load an assembly that still carries the
            # "downloaded from the internet" mark (0x80131515 / "network
            # location"), which is what a DLL from a downloaded ZIP has.
            blocked = _blocked_count(folder)
            if blocked:
                cleared = _unblock_folder(folder)
                left    = _blocked_count(folder)
                log(f"mark-of-the-web: {blocked} blocked file(s), cleared {cleared}")
                if left:
                    log(f"  -> {left} still blocked (needs admin). Run once:")
                    log(f'     Get-ChildItem "{folder}" -Recurse | Unblock-File')

            sys.path.append(folder)
            try:
                os.add_dll_directory(folder)               # HidSharp etc.
            except Exception:
                pass
            clr.AddReference(dll)

            from LibreHardwareMonitor.Hardware import (    # type: ignore
                Computer, HardwareType, SensorType,
            )
            comp = Computer()
            comp.IsCpuEnabled    = True
            comp.IsGpuEnabled    = True
            comp.IsMemoryEnabled = True
            comp.Open()

            self.Computer     = Computer
            self.HardwareType = HardwareType
            self.SensorType   = SensorType
            self.computer     = comp
            self.ok           = True
            log(f"LibreHardwareMonitor loaded: {dll}")
        except Exception as e:
            first = str(e).splitlines()[0] if str(e) else repr(e)
            log(f"LibreHardwareMonitor unavailable: {first}")
            msg = str(e)
            if ("network location" in msg or "0x80131515" in msg
                    or "LoadFrom" in msg):
                log("  -> the DLL is still blocked by Windows. Run this once:")
                log('     Get-ChildItem "C:\\Program Files\\LibreHardwareMonitor" '
                    '-Recurse | Unblock-File')

    # -- internals ---------------------------------------------------------
    @staticmethod
    def _sensors(hw) -> list:
        out = list(hw.Sensors)
        for sub in hw.SubHardware:
            try:
                sub.Update()
            except Exception:
                pass
            out.extend(sub.Sensors)
        return out

    @staticmethod
    def _find(sensors, stype, *names):
        """First sensor of 'stype' whose name contains one of 'names'."""
        for s in sensors:
            if s.SensorType != stype or not s.Value:
                continue
            n = (s.Name or "").lower()
            for want in names:
                if want in n:
                    return float(s.Value)
        return None

    # -- collect ------------------------------------------------------------
    def apply(self, m: Metrics) -> None:
        if not self.ok:
            return
        HT, ST = self.HardwareType, self.SensorType

        for hw in self.computer.Hardware:
            try:
                hw.Update()
            except Exception:
                pass
            sensors = self._sensors(hw)
            ht = hw.HardwareType

            # ---- CPU ----------------------------------------------------
            if ht == HT.Cpu and m.cpu_temp_x10 == NA:
                v = self._find(sensors, ST.Temperature, "package", "core (tctl", "cpu")
                if v is not None:
                    m.cpu_temp_x10 = int(round(v * 10))
                v = self._find(sensors, ST.Power, "package", "cpu")
                if v is not None:
                    m.cpu_power_x10 = int(round(v * 10))

            # ---- GPU ----------------------------------------------------
            elif ht in (HT.GpuNvidia, HT.GpuAmd, HT.GpuIntel):
                v = self._find(sensors, ST.Load, "gpu core", "d3d 3d", "gpu 3d", "core")
                if v is not None:
                    m.gpu = clamp(v)

                v = self._find(sensors, ST.Temperature, "hot spot", "hotspot", "junction")
                if v is not None:
                    m.gpu_hot_x10 = int(round(v * 10))

                v = self._find(sensors, ST.Temperature, "memory", "vram", "hbm")
                if v is not None:
                    m.gpu_memtemp_x10 = int(round(v * 10))

                v = self._find(sensors, ST.Temperature, "gpu core", "core", "edge")
                if v is not None:
                    m.gpu_temp_x10 = int(round(v * 10))

                v = self._find(sensors, ST.Power, "package", "board", "gpu")
                if v is not None:
                    m.gpu_power_x10 = int(round(v * 10))

                v = self._find(sensors, ST.Control, "fan", "gpu")
                if v is None:
                    v = self._find(sensors, ST.Fan, "fan")          # RPM fallback
                if v is not None:
                    m.gpu_fan = clamp(v, 0, 100)

                used = self._find(sensors, ST.SmallData, "gpu memory used", "memory used")
                tot  = self._find(sensors, ST.SmallData, "gpu memory total", "memory total")
                if used is None:
                    u = self._find(sensors, ST.Data, "gpu memory used")
                    used = u * 1024.0 if u is not None else None
                if tot is None:
                    t = self._find(sensors, ST.Data, "gpu memory total")
                    tot = t * 1024.0 if t is not None else None
                if used is not None:
                    m.vram_used_mb = int(used)
                if tot is not None:
                    m.vram_total_mb = int(tot)
                if m.vram_used_mb != NA and m.vram_total_mb and m.vram_total_mb > 0:
                    m.vram = clamp(m.vram_used_mb * 100.0 / m.vram_total_mb)


# ---------------------------------------------------------------------------
# Windows PDH backend (no third-party dependency)
#   Fallback that still provides GPU utilisation + VRAM usage/limit when
#   LibreHardwareMonitor is not installed. Works with AMD / NVIDIA / Intel.
# ---------------------------------------------------------------------------
PDH_FMT_DOUBLE = 0x00000200


class _PdhFmtValue(ctypes.Structure):
    class _U(ctypes.Union):
        _fields_ = [
            ("longValue",       wt.LONG),
            ("doubleValue",     ctypes.c_double),
            ("largeValue",      ctypes.c_longlong),
            ("AnsiStringValue", ctypes.c_char_p),
            ("WideStringValue", ctypes.c_wchar_p),
        ]
    _anonymous_ = ("u",)
    _fields_ = [("CStatus", wt.DWORD), ("u", _U)]


class _PdhItem(ctypes.Structure):
    _fields_ = [("szName", ctypes.c_wchar_p), ("FmtValue", _PdhFmtValue)]


def _pdh_array(handle) -> list[tuple[str, float]]:
    """Read a wildcard PDH counter as a list of (instance, value)."""
    pdh = ctypes.windll.pdh
    size, count = wt.DWORD(0), wt.DWORD(0)
    pdh.PdhGetFormattedCounterArrayW(handle, PDH_FMT_DOUBLE,
                                     ctypes.byref(size), ctypes.byref(count), None)
    if size.value == 0:
        return []
    buf = ctypes.create_string_buffer(size.value)
    rc = pdh.PdhGetFormattedCounterArrayW(handle, PDH_FMT_DOUBLE,
                                          ctypes.byref(size), ctypes.byref(count), buf)
    if rc != 0:
        return []
    items = ctypes.cast(buf, ctypes.POINTER(_PdhItem))
    out = []
    for i in range(count.value):
        try:
            out.append((items[i].szName or "", float(items[i].FmtValue.doubleValue)))
        except Exception:
            pass
    return out
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

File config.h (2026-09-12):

/**
 * ============================================================================
 *  config.h  -  Central configuration for the UART Volume Controller
 * ============================================================================
 *  Everything you are likely to want to tweak lives in this one file:
 *    - pin map
 *    - animation (GIF) table + the per-animation colour palette
 *    - on-screen layout / geometry of the gauges (arcs)
 *    - timing constants
 *    - FreeRTOS task placement and priorities
 *
 *  The TFT_eSPI display pins are NOT here - they live in the library's
 *  User_Setup.h (GC9A01, HSPI: MOSI 11 / SCLK 12 / CS 10 / DC 14 / RST 15).
 *  Do not move them here, they must stay in User_Setup.h.
 * ============================================================================
 */
#pragma once

#include <stdint.h>

// ============================================================================
//  1. IDENTITY / SERIAL PROTOCOL
// ============================================================================
#define FW_NAME              "VolumeControllerUART"
#define FW_PROTOCOL_VERSION  1
#define UART_BAUD            921600     // USB-CDC ignores this, kept for a classic UART
#define RX_LINE_MAX          192        // longest accepted command line
#define RX_STALE_MS          1500       // no PC traffic for this long -> link marked down
#define TX_QUEUE_LEN         32

// ============================================================================
//  2. PIN MAP
// ============================================================================
// ---- Rotary encoder (quadrature, interrupt driven) -------------------------
#define PIN_ENC_A            5
#define PIN_ENC_B            4
#define PIN_ENC_BTN          17   // the encoder's own push switch (was "btnChangeAnim")

// ---- Dedicated media buttons ----------------------------------------------
#define PIN_BTN_PLAY         6
#define PIN_BTN_NEXT         7
#define PIN_BTN_PREV         8

// ---- Reserved "shortcut" buttons (hardware not fitted yet) -----------------
// Pulled up, active LOW, so an unwired pin simply reads HIGH and never fires.
// Set ENABLE_SHORTCUT_BUTTONS to 0 to reclaim the pins/footprint.
#define ENABLE_SHORTCUT_BUTTONS 1
#define PIN_SC_MONITOR       21   // jump straight to the resource monitor
#define PIN_SC_VOLUME        38   // jump straight to the volume page
#define PIN_SC_MEDIA         47   // jump straight to the media page
#define PIN_SC_GALLERY       48   // jump straight to the animation picker

// ============================================================================
//  3. ANIMATION TABLE + COLOUR PALETTE
// ============================================================================
//  Each entry maps to LittleFS files "<prefix>_<n>.raw" (240x240 RGB565,
//  little endian, as produced by the project's img_to_565.py).
//
//   accent    : main UI colour of the animation (outlines, gauge track)
//   highlight : brighter colour used for the SELECTED element / filled gauge
//   tint      : very dark colour used to fill gauge backgrounds
//
//  Tweak these freely - this is the single palette you asked for.
// ----------------------------------------------------------------------------
struct GifPreset {
  const char* prefix;    // LittleFS filename prefix, without the "_n.raw"
  uint8_t     frames;    // number of frames on disk (0 or 1 == single still)
  uint8_t     fps;       // target playback rate
  uint16_t    accent;    // main colour
  uint16_t    highlight; // selected / active colour
  uint16_t    tint;      // dark background fill for gauges
};

#define GIF_COUNT 5
static const GifPreset GIF_TABLE[GIF_COUNT] = {
  // prefix            frames fps   accent   highlight tint
  { "cirilla",           19,  20,  0x738E,  0xC618,  0x18E3 }, // silver / neutral
  { "2b",                15,  60,  0x501F,  0x9C9F,  0x1004 }, // violet
  { "lucycigarette",     24,  20,  0xB81F,  0xFBBF,  0x2804 }, // pink
  { "lucydavidmoon",      1,   5,  0xC617,  0xFEA0,  0x2980 }, // amber
  { "lucybg",             1,   5,  0x4FE4,  0x97F3,  0x0A61 }, // green
};

// ============================================================================
//  4. LAYOUT / GEOMETRY  (240x240 round GC9A01)
// ============================================================================
#define SCR_W                240
#define SCR_H                240
#define SCR_CX               (SCR_W / 2)
#define SCR_CY               (SCR_H / 2)
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

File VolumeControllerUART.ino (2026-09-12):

/**
 * ============================================================================
 *  VolumeControllerUART.ino  -  ESP32-S3 (N16R8) UART volume controller
 * ============================================================================
 *  A rewrite of the original USB-HID volume controller:
 *    - no USB HID   : a line based UART protocol talks to pc/controller.py
 *    - dual core    : core 0 = comms + input, core 1 = renderer
 *    - arc UI       : CPU / RAM / GPU / VRAM gauges plus volume and media pages
 *
 *  See README.md for the wiring, the protocol and the PC-side tool.
 *
 *  NOTE: the display pins live in the TFT_eSPI User_Setup.h (GC9A01) and the
 *        frames live in LittleFS - neither is touched by this project.
 * ============================================================================
 */
#include "config.h"
#include "state.h"
#include "display.h"
#include "comms.h"
#include "input.h"
#include "anim.h"
#include "ui.h"

#include <LittleFS.h>

// ---------------------------------------------------------------------------
//  Shared animation player (owned by the render task)
// ---------------------------------------------------------------------------
static Animation gAnim;

// ===========================================================================
//  Core 1 : renderer  (animation + UI -> panel)
// ===========================================================================
static void taskRender(void* arg) {
  (void)arg;

  for (;;) {
    const bool loaded = gAnim.tick(gFrameBuf);        // LittleFS -> frame buffer (fps gated)
    if (uiRender(gAnim, loaded)) displayPush();       // UI -> sprite -> panel
    vTaskDelay(pdMS_TO_TICKS(5));
  }
}

// ===========================================================================
//  Storage report (setup only - never run after the PC link is live)
// ===========================================================================
static void reportStorage(void) {
  const size_t total = LittleFS.totalBytes();
  const size_t used  = LittleFS.usedBytes();
  const size_t freeB = total - used;

  Serial.println("--- Storage ---");
  Serial.printf("Total : %.2f MB\n", total / (1024.0 * 1024.0));
  Serial.printf("Used  : %.2f MB\n", used  / (1024.0 * 1024.0));
  Serial.printf("Free  : %.2f MB (~%d frames)\n",
                freeB / (1024.0 * 1024.0), (int)(freeB / 115200));
}

// ===========================================================================
//  setup
// ===========================================================================
void setup() {
  Serial.begin(UART_BAUD);
#if defined(ARDUINO_USB_CDC_ON_BOOT) && ARDUINO_USB_CDC_ON_BOOT
  Serial.setTxTimeoutMs(0);                // never block on USB CDC writes
#endif
  Serial.printf("\n%s  protocol %d\n", FW_NAME, FW_PROTOCOL_VERSION);

  // 1. IPC primitives must exist before any task is created
  stateInit();

  // 2. LittleFS (the animation frames)
  if (!LittleFS.begin(true)) Serial.println("LittleFS mount FAILED");
  else                       reportStorage();

  // 3. display: panel + 16bpp sprite + the two PSRAM frame buffers
  if (!displayInit()) Serial.println("displayInit FAILED (PSRAM?)");

  // 4. peripherals and the UART protocol
  inputInit();
  commInit();

  // 5. animation + UI state
  gAnim.begin(0);
  uiInit(&gAnim);

  // 6. paint the first frame so the panel is never blank
  const bool firstFrame = gAnim.tick(gFrameBuf);
  if (uiRender(gAnim, firstFrame)) displayPush();

  // 7. dual-core task layout
  xTaskCreatePinnedToCore(taskComm,   "comm",   TASK_STACK_COMM,   nullptr,
                          TASK_PRIO_COMM,   nullptr, CORE_COMM);
  xTaskCreatePinnedToCore(taskInput,  "input",  TASK_STACK_INPUT,  nullptr,
                          TASK_PRIO_INPUT,  nullptr, CORE_COMM);
  xTaskCreatePinnedToCore(taskRender, "render", TASK_STACK_RENDER, nullptr,
                          TASK_PRIO_RENDER, nullptr, CORE_RENDER);
}

// ===========================================================================
//  loop : the Arduino loop task only idles - all work happens in the pinned
//         FreeRTOS tasks created in setup().
// ===========================================================================
void loop() {
  vTaskDelay(pdMS_TO_TICKS(1000));
}

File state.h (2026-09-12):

/**
 * ============================================================================
 *  state.h  -  Shared runtime state + inter-task communication primitives
 * ============================================================================
 *  Threading contract:
 *    - gState is ONLY touched while holding gStateMtx (use stateLock()/stateUnlock())
 *    - taskInput  -> gInputQ  (InputEvent)      -> consumed by the renderer
 *    - renderer   -> gOutQ    (OutMsg)          -> consumed by taskComm (UART TX)
 * ============================================================================
 */
#pragma once

#include <Arduino.h>
#include <freertos/FreeRTOS.h>
#include <freertos/queue.h>
#include <freertos/semphr.h>
#include "config.h"

// ---------------------------------------------------------------------------
//  Enumerations
// ---------------------------------------------------------------------------
enum Page : uint8_t { PAGE_MONITOR = 0, PAGE_VOLUME, PAGE_MEDIA, PAGE_GALLERY, PAGE_COUNT };
enum Mode : uint8_t { MODE_IDLE = 0, MODE_MENU, MODE_MONITOR, MODE_DETAIL, MODE_VOLUME, MODE_MEDIA, MODE_GALLERY };
enum Comp : uint8_t { COMP_CPU = 0, COMP_RAM, COMP_GPU, COMP_VRAM, COMP_COUNT };

// Input events: produced by taskInput, consumed by the renderer/UI logic
enum EvType : uint8_t {
  EV_ENC_CW = 0, EV_ENC_CCW, EV_BTN_SHORT, EV_BTN_LONG,
  EV_MKEY_PLAY, EV_MKEY_NEXT, EV_MKEY_PREV,
  EV_SC_MONITOR, EV_SC_VOLUME, EV_SC_MEDIA, EV_SC_GALLERY
};
struct InputEvent { EvType type; };

// Outgoing messages: produced by the renderer, consumed by taskComm
enum OutType : uint8_t {
  OUT_HELLO = 0, OUT_VOL_STEP, OUT_VOL_SET, OUT_MUTE_SET, OUT_MEDIA, OUT_REQ_DETAIL, OUT_PAGE
};
enum MediaKey : uint8_t { MK_PLAYPAUSE = 0, MK_NEXT, MK_PREV };
struct OutMsg { OutType type; int16_t a; int16_t b; };
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

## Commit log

2026-09-12 Initial commit for the project
    [partitions.csv]
2026-09-12 ADD CAD files for the case
    [0402_CA_CB_CC_CD.SLDPRT, 2.54 5PIN 90.SLDPRT, AllAssembly.SLDASM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]
2026-09-12 ADD frontplate, made edits
    [AllAssembly.SLDASM, ESP32-S3-WROOM-1.SLDASM, USB-C.SLDASM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]
